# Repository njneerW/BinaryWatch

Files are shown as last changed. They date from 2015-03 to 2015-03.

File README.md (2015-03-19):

# BinaryWatch
TODO:
code is complex enough that it should not be contained entirely in one file.
Seperate out by functionality.

    *display functions
    *RTCC functions
    *deep sleep functions
    *timer functions

Debounce function is actually pretty useful.  Make a library out of it.

    *See if the timers are similar enough that a timer struct can be passed
     in to make the function more generic
    *Pass in the port for the button to debounce (w/ active high v low)
    *Parameterize DEBOUNCE, and HOLD values
    *Make a pushbutton structure, obviating the need for global state vars

If we're making libraries, lets do something about RTCC.  It's begging
    for a simple API interface.

Start properly using the RTCC lock/unlock capability to protect RTCC from
    unintentional modifications.

PIC18F24J11 driven LED binary wrist watch.

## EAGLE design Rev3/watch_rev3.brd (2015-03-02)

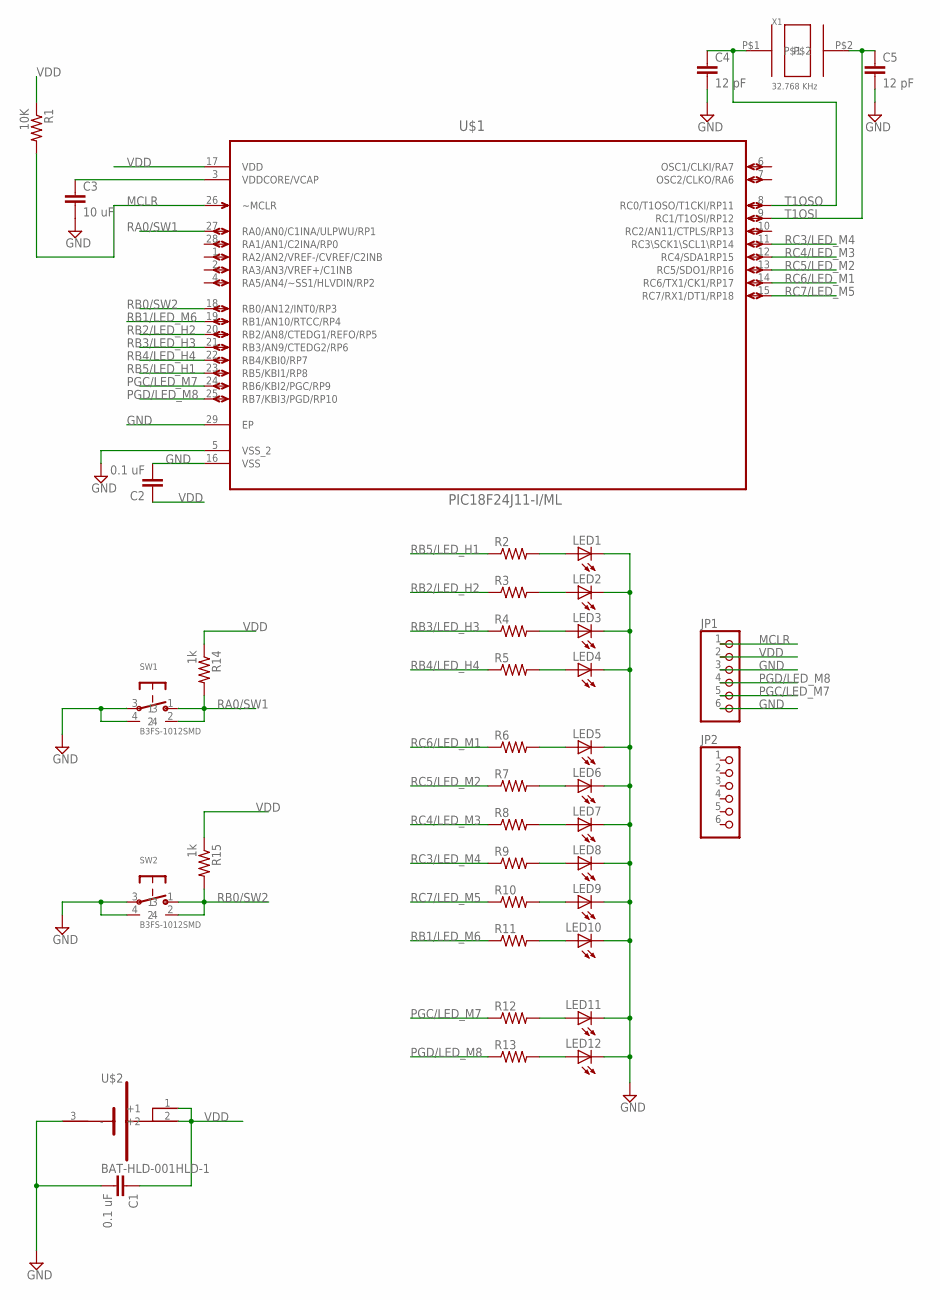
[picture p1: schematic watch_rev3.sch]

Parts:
C1, C2: 0.1 uF; C0603
C3: 10 uF; C0603
C4, C5: 12 pF; C0603
JP1, JP2: PINHD-1X6; 1X06
LED1, LED2, LED3, LED4, LED5, LED6, LED7, LED8, LED9, LED10, LED11, LED12: LEDCHIPLED_0603; CHIPLED_0603
R1: 10K; R0603
R2, R3, R4, R5, R6, R7, R8, R9, R10, R11, R12, R13: R-US_R0603; R0603
R14, R15: 1k; R0603
SW1, SW2: B3FS-1012SMD; B3FS-1012
U$1: PIC18F24J11-I/ML; QFN65P600X600X100-29N
U$2: BAT-HLD-001HLD-1; BAT-HLD-001
X1: 32.768 KHz; XTAL_3.2X1.5

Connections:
GND: C1.2, C2.2, C3.2, C4.2, C5.2, JP1.3, JP1.6, LED1.C, LED2.C, LED3.C, LED4.C, LED5.C, LED6.C, LED7.C, LED8.C, LED9.C, LED10.C, LED11.C, LED12.C, SW1.3, SW1.4, SW2.3, SW2.4, U$1.5 (VSS_2), U$1.16 (VSS), U$1.29 (EP), U$2.3 (-)
MCLR: JP1.1, R1.2, U$1.26 (~MCLR)
unnamed: LED1.A, R2.2
unnamed: LED2.A, R3.2
unnamed: C3.1, U$1.3 (VDDCORE/VCAP)
unnamed: LED3.A, R4.2
unnamed: LED4.A, R5.2
unnamed: LED5.A, R6.2
unnamed: LED6.A, R7.2
unnamed: LED7.A, R8.2
unnamed: LED8.A, R9.2
unnamed: LED9.A, R10.2
unnamed: LED10.A, R11.2
unnamed: LED11.A, R12.2
unnamed: LED12.A, R13.2
PGC/LED_M7: JP1.5, R12.1, U$1.24 (RB6/KBI2/PGC/RP9)
PGD/LED_M8: JP1.4, R13.1, U$1.25 (RB7/KBI3/PGD/RP10)
RA0/SW1: R14.2, SW1.1, SW1.2, U$1.27 (RA0/AN0/C1INA/ULPWU/RP1)
RB0/SW2: R15.2, SW2.1, SW2.2, U$1.18 (RB0/AN12/INT0/RP3)
RB1/LED_M6: R11.1, U$1.19 (RB1/AN10/RTCC/RP4)
RB2/LED_H2: R3.1, U$1.20 (RB2/AN8/CTEDG1/REFO/RP5)
RB3/LED_H3: R4.1, U$1.21 (RB3/AN9/CTEDG2/RP6)
RB4/LED_H4: R5.1, U$1.22 (RB4/KBI0/RP7)
RB5/LED_H1: R2.1, U$1.23 (RB5/KBI1/RP8)
RC3/LED_M4: R9.1, U$1.11 (RC3\SCK1\SCL1\RP14)
RC4/LED_M3: R8.1, U$1.12 (RC4/SDA1RP15)
RC5/LED_M2: R7.1, U$1.13 (RC5/SDO1/RP16)
RC6/LED_M1: R6.1, U$1.14 (RC6/TX1/CK1/RP17)
RC7/LED_M5: R10.1, U$1.15 (RC7/RX1/DT1/RP18)
T1OSI: C5.1, U$1.9 (RC1/T1OSI/RP12), X1.P$2
T1OSO: C4.1, U$1.8 (RC0/T1OSO/T1CKI/RP11), X1.P$1
VDD: C1.1, C2.1, JP1.2, R1.1, R14.1, R15.1, U$1.17 (VDD), U$2.1 (+1), U$2.2 (+2)

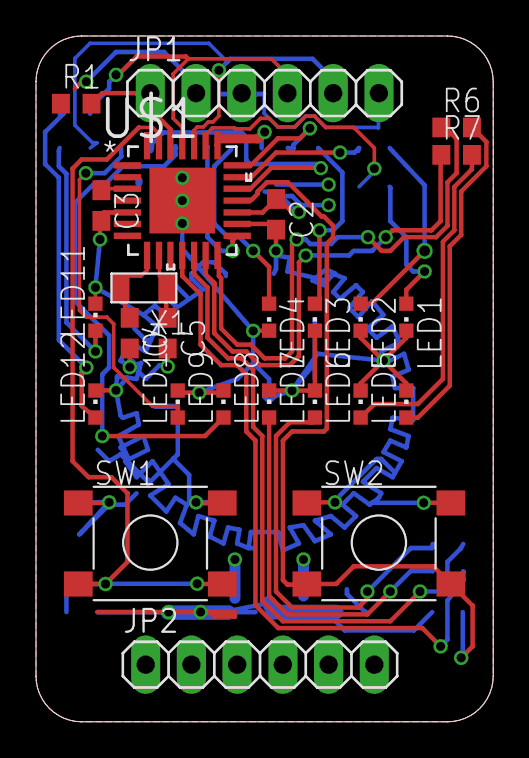
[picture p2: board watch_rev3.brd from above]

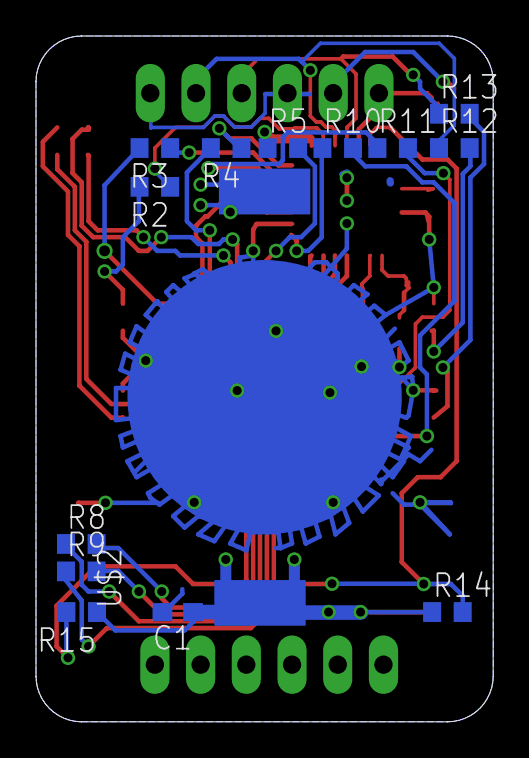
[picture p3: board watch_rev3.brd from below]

Board: 2 copper layers, 25.4 x 38.1 mm, 39 parts (14 on the bottom side), 32 nets.

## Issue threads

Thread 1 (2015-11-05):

Incorrect pin layout for upper LEDs

olchri, 2015-11-05:
Row 155-157: Upper LED 2-4 are all matched to pin U_L1

njneerW, 2015-11-05:
What net(s) are you referring to?  I see all upper LEDs cathodes tied to ground, which is intentional, but the anodes all have independent nets tied to their respective current limiting resistors.

olchri, 2015-11-05:
Ah sorry, I was unclear. Kinda new to git. The issue is in the firmware
main.c , in your last commit all upper leds are assigned to the same pin.
Row 155.
Den 5 nov 2015 17:27 skrev "njneerW" <notifications@github.com>:

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

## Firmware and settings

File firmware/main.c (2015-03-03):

/*
 * File:   main.c
 * Author: Jordan Wills
 *
 * Created on October 9, 2014, 1:50 PM
 *
 * This program causes the PIC to act as a binary clock.  The following list
 * details the functionality of each pin in the system.  If a pin is not listed,
 * it is assumed to be unused.
 *
 * A0: Pushbutton 1.  Ultra low power wake used for deep sleep wake on btn press
 *
 * B0: Pushbutton 0.  INT0 used for deep sleep wake on button press
 * B1: Lower LED row digit 6 (minutes "32")
 * B2: Upper LED row digit 2 (hours "2")
 * B3: Upper LED row digit 3 (hours "4")
 * B4: Upper LED row digit 4 (hours "8")
 * B5: Upper LED row digit 1 (hours "1")
 * B6: Date LED / programmer clock (PGC)
 * B7: Time LED / programmer data (PGD)
 *
 * C0: RTCC crystal OSO
 * C1: RTCC crystal OSI
 * C3: Lower LED row digit 4 (minutes "8")
 * C4: Lower LED row digit 3 (minutes "4")
 * C5: Lower LED row digit 2 (minutes "2")
 * C6: Lower LED row digit 1 (minutes "1")
 * C7: Lower LED row digit 5 (minutes "16")
 *
 * The following list details the functionality of various peripherals:
 * Timer0: Debounce Pushbutton 0
 * Timer1: Debounce Pushbutton 1
 * Timer2: LED change animation
 * Timer3: During "set" mode, blinks the row currently being modified
 */

/******************************************************************************
 * Software License Agreement
 *
 * Copyright © 2014 Jordan Wills.  All rights reserved.
 *
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
 *****************************************************************************/
#include <p18f24j11.h>

#pragma config WDTEN = OFF, OSC = INTOSC, RTCOSC = T1OSCREF, XINST = OFF

//*****************************************************************************
// Chip wide defines
//*****************************************************************************
//
// Calibration settings
//
#define CONFIG_BUILD        0
#define RTCCAL_VAL          0

//
// Clock values
//
#define INTOSC_FREQ         ((unsigned long)4000000)

//
// Timer0 and PB0
//
#define T0_PSCALE           16
#define T0_PSCALE_BITS      0x3
#define T0_uS_PER_TICK      16
// debounce = debounce time(uS) / 16
#define T0_DEBOUNCE         3125
// hold = hold time(uS) / 16
#define T0_HOLD             62500
//
// Timer1 and PB1
//
#define T1_PSCALE           1
#define T1_PSCALE_BITS      0x0
#define T1_uS_PER_TICK      30
// debounce = debounce time(uS) / 8
#define T1_DEBOUNCE         1640
// hold = hold time(uS) / 8
#define T1_HOLD             32787

//
// Pushbutton state machine defines
//
#define PB_STATE_IDLE       0
#define PB_STATE_DEBOUNCING 1
#define PB_STATE_MID_PRESS  2
#define PB_STATE_HELD       3
#define PB_STATE_RELEASED   4

//
// LED display states
//
#define DISP_STATE_TIME_S   0
#define DISP_STATE_TIME_H   1
#define DISP_STATE_DATE     2
#define DISP_STATE_SET_TIME 3
#define DISP_STATE_SET_DATE 4

//
// set time states
//
#define SET_STATE_LOWER 0
#define SET_STATE_UPPER 1

//
// LED port and pin definitions
//
#define PB0_PORT        PORTB
#define PB0_PORT_BITS   PORTBbits
#define PB0_PIN         RB0
#define PB0             PB0_PORT_BITS.PB0_PIN

#define PB1_PORT        PORTA
#define PB1_PORT_BITS   PORTAbits
#define PB1_PIN         RA0
#define PB1             PB1_PORT_BITS.PB1_PIN

#define L_ROW_PORT      PORTC
#define L_ROW_PORT_PINS PORTCbits
#define L6_PORT         PORTB
#define L6_PORT_PINS    PORTBbits
#define L_L1_PIN        RC6
#define L_L2_PIN        RC5
#define L_L3_PIN        RC4
#define L_L4_PIN        RC3
#define L_L5_PIN        RC7
#define L_L6_PIN        RB1
#define LED_L1          L_ROW_PORT_PINS.L_L1_PIN
#define LED_L2          L_ROW_PORT_PINS.L_L2_PIN
#define LED_L3          L_ROW_PORT_PINS.L_L3_PIN
#define LED_L4          L_ROW_PORT_PINS.L_L4_PIN
#define LED_L5          L_ROW_PORT_PINS.L_L5_PIN
#define LED_L6          L6_PORT_PINS.L_L6_PIN

#define U_ROW_PORT      PORTB
#define U_ROW_PORT_PINS PORTBbits
#define U_L1_PIN        RB5
#define U_L2_PIN        RB2
#define U_L3_PIN        RB3
#define U_L4_PIN        RB4
#define LED_U1          U_ROW_PORT_PINS.U_L1_PIN
#define LED_U2          U_ROW_PORT_PINS.U_L1_PIN
#define LED_U3          U_ROW_PORT_PINS.U_L1_PIN
#define LED_U4          U_ROW_PORT_PINS.U_L1_PIN

#define DT_PORT         PORTB
#define DT_PORT_PINS    PORTBbits
#define DT_TIME_PIN     RB7
#define DT_DATE_PIN     RB6
#define LED_DATE        DT_PORT_PINS.DT_DATE_PIN
#define LED_TIME        DT_PORT_PINS.DT_TIME_PIN

//
// Type for mapping out bits of dleep sleep persistent memory byte0
//
typedef union t_DSGPR0map
{
    struct
    {
        //
        // No matter how much I use a PIC, I will never be comfortable with
        // using bitfields
        //
        unsigned char PB0State : 2;
        unsigned char PB1State : 2;
    };
    unsigned char ucRaw;
} DSGPR0map;

//
// Type for mapping out bits of dleep sleep persistent memory byte1
//
typedef union t_DSGPR1map
{
    struct
    {
        unsigned char dispState : 3;
        unsigned char setState : 1;
        unsigned char blinkState : 1;
        unsigned char blackout : 1;
    };
    unsigned char ucRaw;
} DSGPR1map;

//
// Macros for deep sleep fields... deprecated by bit fields
//
#define PB0_DSREG           DSGPR0
#define PB0_STATE_MASK      0x03
#define PB0_STATE_SHIFT     0

#define PB1_DSREG           DSGPR0
#define PB1_STATE_MASK      0x0C
#define PB1_STATE_SHIFT     2

#define DISP_STATE_DSREG    DSGPR1
#define DISP_STATE_MASK     0x07
#define DISP_STATE_SHIFT    0

#define DISP_BLINK_DSREG    DSGPR1
#define DISP_BLINK_MASK     0x08
#define DISP_BLINK_SHIFT    3

//*****************************************************************************
// Global variables
//*****************************************************************************
unsigned char g_ucPB0State = PB_STATE_IDLE;
unsigned char g_ucPB1State = PB_STATE_IDLE;
volatile unsigned char g_ucNapTime = 0;
DSGPR0map g_sDSGPR0;
DSGPR1map g_sDSGPR1;

//*****************************************************************************
// Function prototypes
//*****************************************************************************
void PressPB0(void);
void HoldPB0(void);
void PressPB1(void);
void HoldPB1(void);
int displayTime(void);

//*****************************************************************************
//  CODE CODE CODE CODE CODE CODE CODE CODE CODE CODE CODE CODE CODE CODE CODE
//*****************************************************************************

//*****************************************************************************
//
// These should never be entered.  If we get here, something has gone awry.  In
// release mode, do nothing.  In dev mode, turn on & hold the date and time
// LEDs to signify that bad has occurred.
//
//*****************************************************************************
//#pragma interrupt HiISR
void HiISR(void)
{
    LED_DATE = 1;
    LED_TIME = 1;
    //while(1);
}

//#pragma interruptlow LoISR
void LoISR(void)
{
    LED_DATE = 1;
    LED_TIME = 1;
    //while(1);
}

//*****************************************************************************
//
// Configure the GPIOs.  Note that this gets called on both cold boot and deep
// sleep wake, so don't set anything here that you don't want done on a DS wake
// (like default LED values)
//
//*****************************************************************************
void configGPIOs(void)
{
    //
    // Set all GPIOs as digital, not analog
    //
    ANCON0 = 0xFF;
    ANCON1 = 0x1F;

    //
    // Set PA0 to input, PA1..7 as output
    //
    TRISA = 1;

    //
    // Set PB0 to input, PB1..7 as output
    //
    TRISB = 1;

    //
    // Set port b to enable weak pull-up
    //
    INTCON2bits.NOT_RBPU = 1;

    //
    // Set all PC to output
    //
    TRISC = 0;

    //
    // Set unused ports to drive low, per low power recommendations in datasheet
    //
    PORTCbits.RC2 = 0;
    PORTAbits.RA1 = 0;
    PORTAbits.RA2 = 0;
    PORTAbits.RA3 = 0;
    PORTAbits.RA5 = 0;

}

//*****************************************************************************
//
// Configure the Real time clock/calendar peripheral.
//
//*****************************************************************************
void configRTCC(void)
{
    //
    // unlock writes to the RTCC
    //
    EECON2 = 0x55;
    EECON2 = 0xAA;
    RTCCFGbits.RTCWREN = 1;

    //
    // enable the RTCC, set pointers to read seconds and minutes
    //
    RTCCFGbits.RTCEN = 1;
    RTCCFGbits.RTCPTR0 = 0;
    RTCCFGbits.RTCPTR1 = 0;

    //
    // enable the RTCC alarm, chime @ 1 Hz
    //
    ALRMCFGbits.CHIME = 1;
    ALRMCFGbits.AMASK0 = 1;
    ALRMCFGbits.AMASK1 = 0;
    ALRMCFGbits.AMASK2 = 0;
    ALRMCFGbits.AMASK3 = 0;
    ALRMCFGbits.ALRMEN = 1;
}

//*****************************************************************************
//
// Configure the deep sleep module.  We want to be able to wake from the RTCC,
// INT0, and the ULPWU interrupt.  Also, make sure deep sleep really means deep
// sleep, not low power sleep.
//
//*****************************************************************************
void configDS(void)
{
    WDTCONbits.REGSLP = 1;
    OSCCONbits.IDLEN = 0;
    DSCONHbits.RTCWDIS = 0;
    DSCONHbits.DSULPEN = 0;
    DSCONLbits.ULPWDIS = 0;
}

//*****************************************************************************
//
// Configure Timer3.  Source from internal Oscillator, maximum prescaler, enable
// 16 bit mode.
//
//*****************************************************************************
void configTimer3(void)
{
    //
    // set source to intOSC/4, 1 MHz
    //
    T3CONbits.TMR3CS = 0;

    //
    // Set prescaler to 1:8
    //
    T3CONbits.T3CKPS = 0x3;

    //
    // Enable 16 bit operations
    //
    T3CONbits.RD16 = 1;

    //
    // zero out timer
    //
    TMR3H = 0;
    TMR3L = 0;

    //
    // Turn on timer
    //
    //T3CONbits.TMR3ON = 1;

    return;
}

//*****************************************************************************
//
// Configure Timer1.  Source from T1OSC (external 32.768 crystal), no prescaler,
// 8 bit width, no counting/gating
//
//*****************************************************************************
void configTimer1(void)
{
    //
    // set source to T1OSC (T1CKI pin)
    //
    T1CONbits.TMR1CS = 2;
    
    //
    // set the prescaler to 0, giving us a max timeout of 2 s
    //
    // set prescaler to 1:1, giving us a range of:
    //   (1/32.768KHz) * prescaler = 30.5 us per tick
    //   1 = 30.5 uS, 0xFFFF = 2 s
    //
    T1CONbits.T1CKPS = 0x0;
    
    //
    // Enable T1 external oscillator
    //
    T1CONbits.T1OSCEN = 1;

    //
    // Set timer to 8 bit width
    //
    T1CONbits.RD16 = 1;

    //
    // Make sure T1 gate is diabled
    //
    T1GCONbits.TMR1GE = 0;

    PIR1bits.TMR1IF = 0;
    PIE1bits.TMR1IE = 0;
    T1CONbits.TMR1ON = 0;
}

//*****************************************************************************
//
// Configure Timer2.  Source from internal Oscillator, 1:16 prescaler
//
//*****************************************************************************
void configTimer2(void)
{
    //
    // Set prescaler to 1:16
    //
    T2CONbits.T2CKPS = 0x2;

    //
    // zero out timer
    //
    TMR2 = 0;
}

//*****************************************************************************
//
// Configure Timer0.  Source from internal Oscillator, 1:16 prescaler, enable
// 8 bit mode.
//
//*****************************************************************************
void configTimer0(void)
{
    //
    // set source to intOSC
    //
    T0CONbits.T0CS = 0;
    T0CONbits.T08BIT = 0;

    //
    // set prescaler to 1:16, giving us a range of:
    //   (1/4MHz * 4) * prescaler = 16 us per tick
    //   1 = 16 uS, 0xFFFF = 1.05 s
    //
    T0CONbits.T0PS = 0x03;
    T0CONbits.PSA = 0;

    //
    // Always write TMR0H before writing TMR0L
    //
    TMR0H = 0;
    TMR0L = 0;

    //
    // enable timer interrupt
    //
    INTCONbits.TMR0IE = 0;
    INTCONbits.TMR0IF = 0;
}

//*****************************************************************************
//
// This function will cause the system to go into deep sleep mode.  If all goes
// well, this function never returns.  On wake, the system will start executing
// at main.
//
//*****************************************************************************
void enterDS(void)
{
    DSCONHbits.DSULPEN = 1;
    DSGPR0 = g_sDSGPR0.ucRaw;
    DSGPR1 = g_sDSGPR1.ucRaw;
    DSCONHbits.DSEN = 1;
    Sleep();
}
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
void main(void) {
    unsigned char stayUp = 0;

    configDS();
    configRTCC();
    configGPIOs();
    configTimer0();
    configTimer1();
    configTimer2();
    configTimer3();

    //
    // if we woke due to deep sleep, we won't be able to change the GPIO values
    // until we release them from deep sleep lock.
    //
    if(WDTCONbits.DS == 1)
    {
        //
        // Clear deep sleep status bits and release GPIOS from deep sleep lock
        //
        WDTCONbits.DS = 0;
        DSCONLbits.RELEASE = 0;

        //
        // load deep sleep persistent status values from retention register into
        // RAM
        //
        g_sDSGPR0.ucRaw = DSGPR0;
        g_sDSGPR1.ucRaw = DSGPR1;

        //
        // copy debounce states to global variables
        //
        g_ucPB0State = g_sDSGPR0.PB0State;
        g_ucPB1State = g_sDSGPR0.PB1State;

        //
        // Now that we're awake, turn on the LEDs
        //
        displayTime();

        //
        // Determine wake source
        //
        if(DSWAKELbits.DSRTC)
        {
            //
            // Eventually, we might do something nifty here.... I can't think of
            // a functionality to map to this yet.
            //
            // If we're here, we woke up because of RTC chime
        }
        if(DSWAKEHbits.DSINT0)
        {
            //
            // What he said ^
            //
            // If we're here, we woke up because of INT0 status change
            //
        }

    }
    else
    {
        //
        // This isn't a deep sleep wake, it's a full on cold boot.
        //

        //TODO: shouldn't this be moved to the configGPIO function??
        //
        // Init all GPIO outs.
        //
        LATA = 0;
        LATB = 0;
        LATC = 0;

        //
        // Init deep sleep persistent variables
        //
        g_sDSGPR0.PB0State = PB_STATE_IDLE;
        g_sDSGPR0.PB1State = PB_STATE_IDLE;
        g_sDSGPR1.blackout = 0;
        g_sDSGPR1.blinkState = 1;
        g_sDSGPR1.dispState = DISP_STATE_TIME_S;
        g_sDSGPR1.setState = SET_STATE_LOWER;
        DSGPR0 = g_sDSGPR0.ucRaw;
        DSGPR1 = g_sDSGPR1.ucRaw;
    }

    //
    // enable global interrupts
    //
    INTCONbits.GIE = 1;
    INTCONbits.PEIE = 1;

    INTCON2bits.INTEDG0 = 1;
    INTCONbits.INT0IF = 0;
    INTCONbits.INT0IE = 1;

    g_ucNapTime = 0;
    stayUp = 0;
    
//#if CONFIG_BUILD == 1
//
// In previous builds, the RTC CLK was routed to to the RTCCFG test point, and
// a special build could be used to sample that output for calibration.  Since
// switching the RTC clock source from INTOSC to accurate external XTAL, this is
// no longer necessary.  Might be useful for reference someday, though.
//
//    //ALRMCFGbits.CHIME = 0;
//    //ALRMCFGbits.ALRMEN = 0;
//    PADCFG1bits.RTSECSEL0 = 0;
//    PADCFG1bits.RTSECSEL1 = 1;
//    RTCCFGbits.RTCOE = 1;
//    while(1);
//#endif

    while (1)
    {

//#define DEBUG 1
#ifdef DEBUG
        //
        // Random one off functionality tests go here
        //
        while(1)
        {
            LATCbits.LATC6 = 1;
            LATCbits.LATC5 = 1;
            LATCbits.LATC7 = 1;
            TRISCbits.TRISC5 = 0;
            TRISCbits.TRISC6 = 0;
            TRISCbits.TRISC7 = 0;
            PORTCbits.RC6 = 1;
            PORTCbits.RC5 = 1;
            PORTCbits.RC7 = 1;
            //updateRows(0xff, 0xff);
        }
        //
        // Set prescaler to 1:4
        //
        T2CONbits.T2CKPS = 0x2;

        //
        // zero out timer
        //
        TMR2 = 0;

        T2CONbits.TMR2ON = 1;

        while(1)

            /*
            //
            // Turn on timer
            //
            //T3CONbits.TMR3ON = 1;
            if(TMR2 >= 0xFF)
            {
                TMR2 = 0;
                stayUp++;
                if(stayUp >= 50)
                {
                    if(toggle)
                    {
                        PORTBbits.RB2 = 1;
                        PORTBbits.RB3 = 1;
                        PORTBbits.RB4 = 1;
                        PORTBbits.RB5 = 1;
                        toggle = 0;
                    }
                    else
                    {
                        PORTBbits.RB2 = 0;
                        PORTBbits.RB3 = 0;
                        PORTBbits.RB4 = 0;
                        PORTBbits.RB5 = 0;
                        toggle = 1;
                    }
                    stayUp = 0;
                }

            }
        }
             * */
        displayTime();

        if(PB0_PORT_BITS.PB0_PIN == 0)
        {
            U_ROW_PORT_PINS.U_L1_PIN = 1;
        }
        else
        {
            U_ROW_PORT_PINS.U_L1_PIN = 0;
        }

        if(PB1_PORT_BITS.PB1_PIN == 0)
        {
            U_ROW_PORT_PINS.U_L2_PIN = 1;
        }
        else
        {
            U_ROW_PORT_PINS.U_L2_PIN = 0;
        }

        if(PORTBbits.RB0)
        {
            INTCON2bits.INTEDG0 = 0;
        }
        else
        {
            INTCON2bits.INTEDG0 = 1;
        }
        if(PB0_PORT_BITS.PB0_PIN == 1)
        {
            while(RTCCFGbits.RTCSYNC);

            //
            // make sure all ints are cleared and enabled, then go to sleep
            //
            //PIR3bits.RTCCIF = 0;
            //PIE3bits.RTCCIE = 0;

            if(INTCONbits.INT0IF)
            {
                INTCONbits.INT0IF = 0;
                if(PORTBbits.RB0)
                {
                    INTCON2bits.INTEDG0 = 0;
                }
                else
                {
                    INTCON2bits.INTEDG0 = 1;
                }
            }
            INTCONbits.TMR0IF = 0;
            PIR1bits.TMR1IF = 0;
            //INTCONbits.INT0IF = 0;
            //INTCONbits.INT0IE = 1;
            //ALRMCFGbits.ALRMEN = 0;
            //ALRMCFGbits.CHIME = 0;
            enterDS();
        }
#else

        //
        // Determine if either button is being interfaced with
        //
        stayUp = 0;
        stayUp += debouncePB0(&PressPB0, &HoldPB0);
        stayUp += debouncePB1(&PressPB1, &HoldPB1);
        
        //
        // Update the display LEDs
        //
        stayUp += displayTime();

        //
        // If the sleep button was held, black out all the lights.  Doing this
        // outside of the below "go to deep sleep" loop gives us the ability to
        // get the LEDs to appear at ~half brightness once the user has held the
        // sleep pushbutton long enough to go to sleep.  This was necessary b/c
        // if we sleep as soon as the user has held the PB long enough, we lose
        // the ability to debounce the PB release.  But if we don't sleep until
        // the PB is released, the user loses the visual feedback letting them
        // know the button has been held long enough for sleep to occur.
        // FIXME: this could cause problems if sleep is held while in the
        //        middle of setting the time...
        // FIXED: JTW: HoldPB0 updated to only change nap time if we're
        //        in a display state
        //
        if(g_ucNapTime)
        {
            PORTC = 0;
            PORTB = 0;
            g_sDSGPR1.blackout = 1;
        }

        //
        // If the push buttons don't need us to stay awake, and we're in a
        // display state (as opposed to a set state), we can go into deep sleep.
        //        
        if( !stayUp &&
            ((g_sDSGPR1.dispState == DISP_STATE_TIME_S) ||
            (g_sDSGPR1.dispState == DISP_STATE_TIME_H) ||
            (g_sDSGPR1.dispState == DISP_STATE_DATE)))
        {
            //
            // determine polarity of PB0, so we can know what edge to wake on
            //
            if(PB0)
            {
                INTCON2bits.INTEDG0 = 0;
            }
            else
            {
                INTCON2bits.INTEDG0 = 1;
            }
            
            //
            // If we're going down because the blackout PB was held, turn off
            // the LEDs and only wake up when a pushbutton is hit again
            //
            if(g_ucNapTime)
            {
                PORTC = 0;
                PORTB = 0;
                ALRMCFGbits.CHIME = 0;
                ALRMCFGbits.ALRMEN = 0;
                INTCON2bits.INTEDG0 = 0;
                g_sDSGPR1.blackout = 1;
            }

            //
            // wait until RTCSYNC is clear
            //
            while(RTCCFGbits.RTCSYNC);

            //
            // make sure all ints are cleared and enabled, then go to sleep
            //
            INTCONbits.INT0IF = 0;
            INTCONbits.INT0IE = 1;
            INTCONbits.TMR0IF = 0;
            PIR1bits.TMR1IF = 0;
            PIR3bits.RTCCIF = 0;
            enterDS();
          }
#endif
    }
}

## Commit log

2015-03-02 Added initial files to github
    [watch_rev3.GBL, watch_rev3.GBO, watch_rev3.GBP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]
2015-03-03 Updated all LED port/pin references to instead use macros. I don't foresee the pinout changing at this point, but that will make it much easier to modify update and read functions if LED port/pins ev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
2015-03-19 Added todo list to README, in case I ever get bored
